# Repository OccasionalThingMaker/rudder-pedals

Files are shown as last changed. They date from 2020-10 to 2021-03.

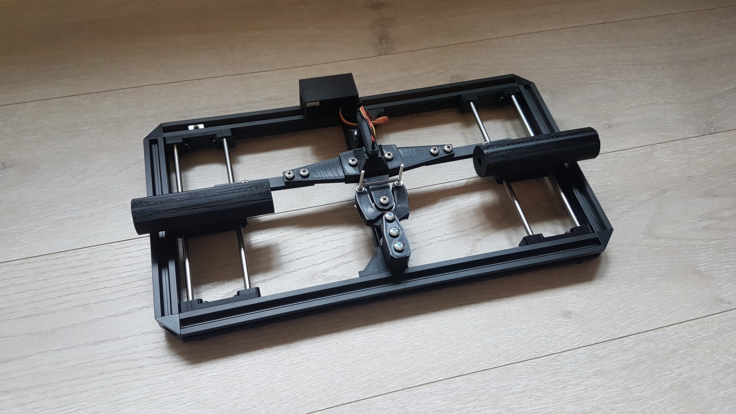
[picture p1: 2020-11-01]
Pictures/1.jpg

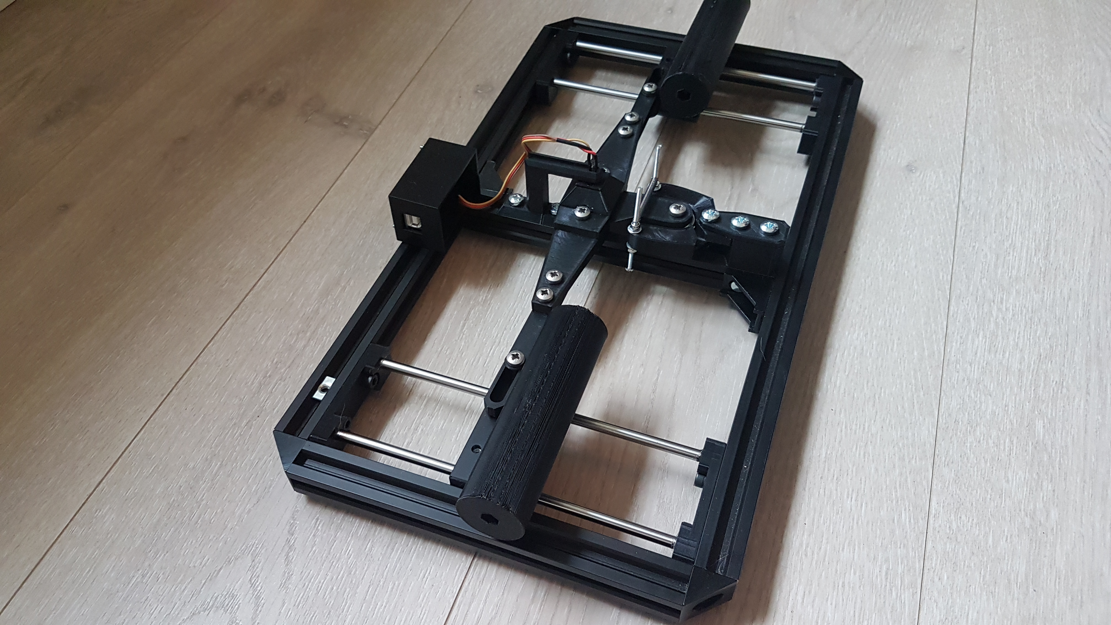
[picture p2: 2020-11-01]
Pictures/2.jpg

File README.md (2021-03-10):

# rudder-pedals

This is an ongoing project where I'm building rudder pedals for use in flight-sims from scratch.
The aim is to have rudder pedals with working brakes, with the pedals themselves modelled after the venerable F14 Tomcat pedals.
The mechanism is made from scratch by yours truly, with inspiration from various sources.

The goal is to make a pair of pedals that are:
* Easy to make (Requiring few tools, and a small 3D printer)
* Reasonably cheap
* Accurate and well functioning
* Free to download

Status as of writing:
The pedals are working and I'm starting to use them while "flying". 
I still have to fix some small details, like the box for the bodnar control board.
I've decided to postpone work on the full pedals with brake mechanism until I've I've finished all the details and the documentation.
The STEP files are not complete, nor checked for faults.

Contact me on reddit:
https://www.reddit.com/user/OccasionalThingMaker/

Check out r/HotasDIY for more inspiration and questions
https://www.reddit.com/r/HotasDIY/

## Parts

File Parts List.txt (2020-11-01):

This is a list of all the parts needed.

THIS LIST IS NOT COMPLETE

List of parts used

20x20 Aluminum extrusion - 2x 40cm, 3x 20cm
20x20 Corner brackets - 4x
20x20 Corner brackets - 2x
20x20
Metal rods - 4x 20cm rods, ø=6mm
LM6UU - 8x
T-nuts - 25-pack
M5 screws
M6 screws - 8x - For the four corners
LeoBodnar BU0836A 12-Bit Joystick Controller
LeoBodnar Hall sensor
Neodymium magnets - 2x

List of tools used
Thread tapper - M6 - For making threads in the extrusions so you can fasten the corner brackets
3D printer
Screw drivers
Soldering iron

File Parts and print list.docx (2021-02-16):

Buy list
Item | Qty | Usage | Picture | Link | Example price

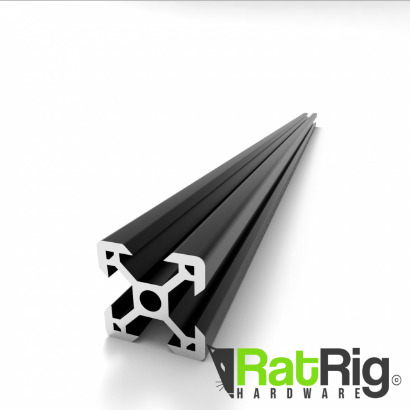
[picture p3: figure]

20x20 Aluminium extrusion 20cm | 3 | To make the frame. | | https://www.ratrig.com/aluminium-profiles/v-slot-2020/v-slot-2020-638.html | €11.25 (for 150cm)
20x20 Aluminium extrusion 40cm | 2

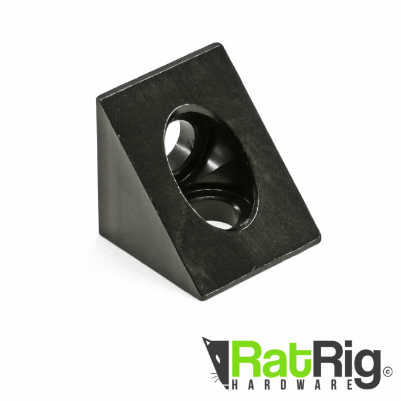
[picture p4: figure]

Corner connector | 4 | To connect the extrusions in the frame. You will need to tap the extrusions to make threads. | | https://www.ratrig.com/hardware2/openbuilds/brackets/openbuilds-90-degree-angle-corner-connector.html | €11.04

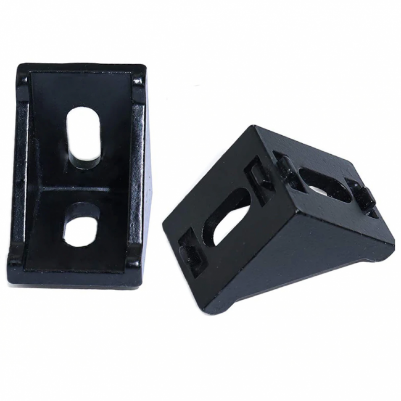
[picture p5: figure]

Corner bracket | 2 | To connect the middle 20cm extrusion. | | https://www.ratrig.com/hardware2/openbuilds/brackets/cast3030-black.html | €1.80

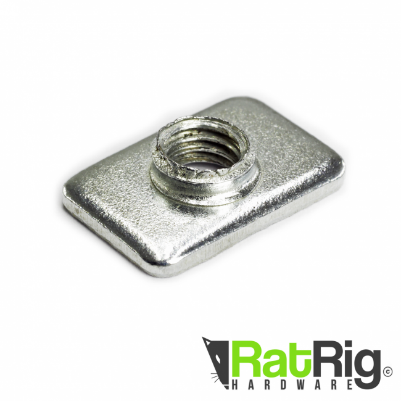
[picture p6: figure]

T-Nuts (25 Pack) | 1 | To connect all the hardware to the extrusions. M5 threads | | https://www.ratrig.com/hardware2/openbuilds/nuts-spacers-washers/openbuilds-tee-nuts-25-pack.html | €4.05

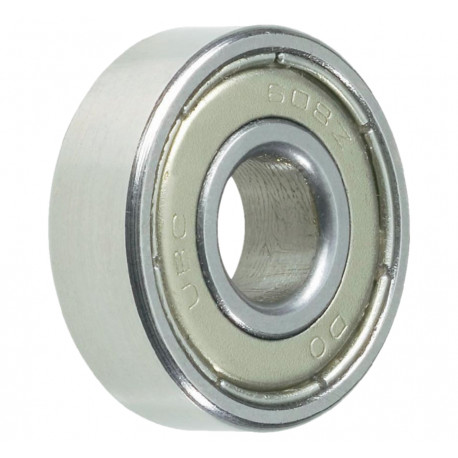
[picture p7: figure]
Bearing 608 2Z

Ball bearing 608Z | 2 | | | https://shop.prusa3d.com/en/mini/1108-bearing-608-2z.html | €2.14

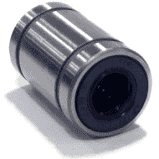
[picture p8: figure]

Linear bearing LM6UU | 8 | To slide on the rods. Need to fit 6mm diameter rods. | | https://www.romasterl.com/index.php?main_page=product_info&products_id=40302 | €24.72
Rubber feet | 4 | | | https://www.ratrig.com/hardware2/openbuilds/general-hardware/slider-bumper-kit-pair.html
Rods 20cm ø=6mm | 4 | For the pedals to slide along.
Spring | 1
mm M5 Screw
mm M5 Screw
mm M5 Screw
mm M5 Screw
M5 nut
M5 Nyloc nut
mm M3 Screw
mm M3 Screw
mm M3 Screw
M3 nut
M3 Nyloc nut

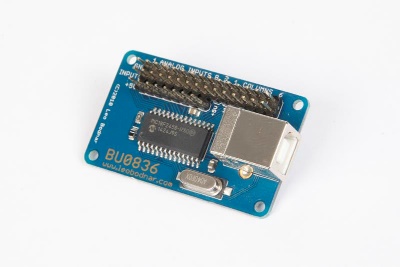
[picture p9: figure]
BU0836A 12-Bit Joystick Controller

BU0836A 12-Bit Joystick Controller | 1 | | | http://www.leobodnar.com/shop/index.php?main_page=product_info&cPath=94&products_id=204 | 24.99

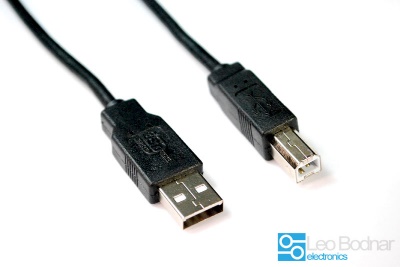
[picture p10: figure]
3m USB A to B cable

USB A to B cable | 1 | | | http://www.leobodnar.com/shop/index.php?main_page=product_info&products_id=270 | 3.87
Magnetic (Hall effect) sensor Allegro A1302 | 1 | | | http://www.leobodnar.com/shop/index.php?main_page=product_info&cPath=103_82&products_id=195 | 2.76

Cable with 3 pin connector plug attached - 30cm ( 12in )

Cable with 3 pin connector plug attached | 1 | | | http://www.leobodnar.com/shop/index.php?main_page=product_info&cPath=83&products_id=202 | 1.65
| | | | | 88,27

Print list
Tool list
3D-printer
Screw drivers
Soldering iron

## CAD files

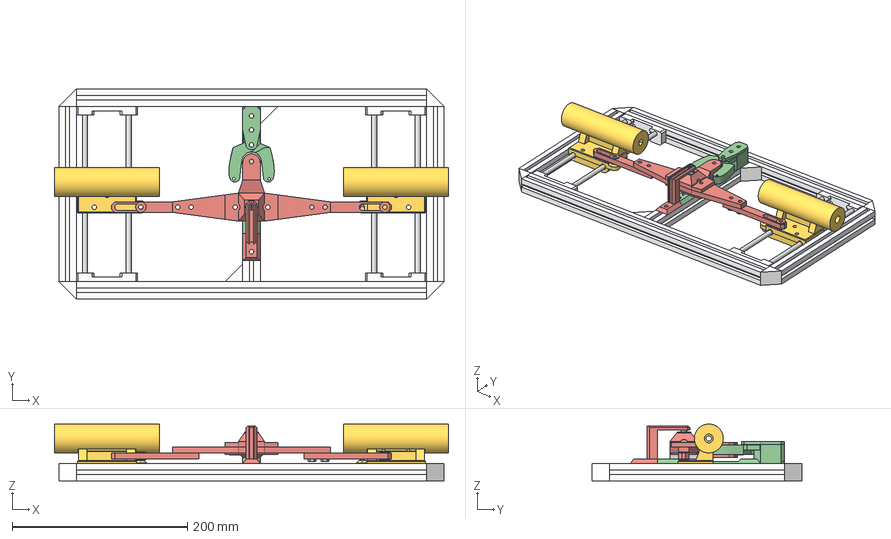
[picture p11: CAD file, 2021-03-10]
STEP files/all pieces.step
449.7 x 240.0 x 65.0 mm
Peddals v10
Peddals v10(Mirror)
Pedal sled v8(Mirror)

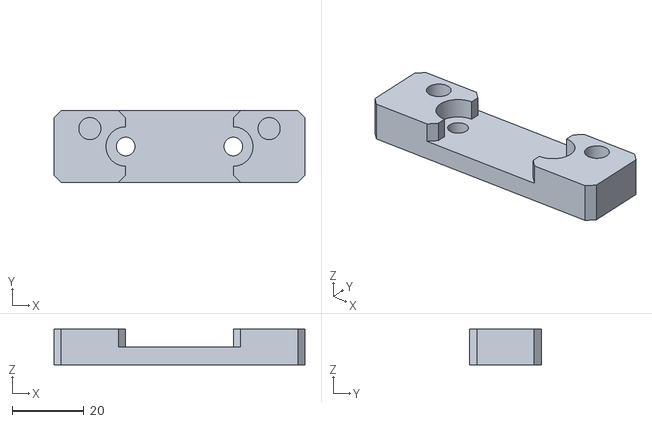
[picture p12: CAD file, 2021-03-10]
STLs/rod-bracket v2.stl
70.0 x 20.0 x 10.0

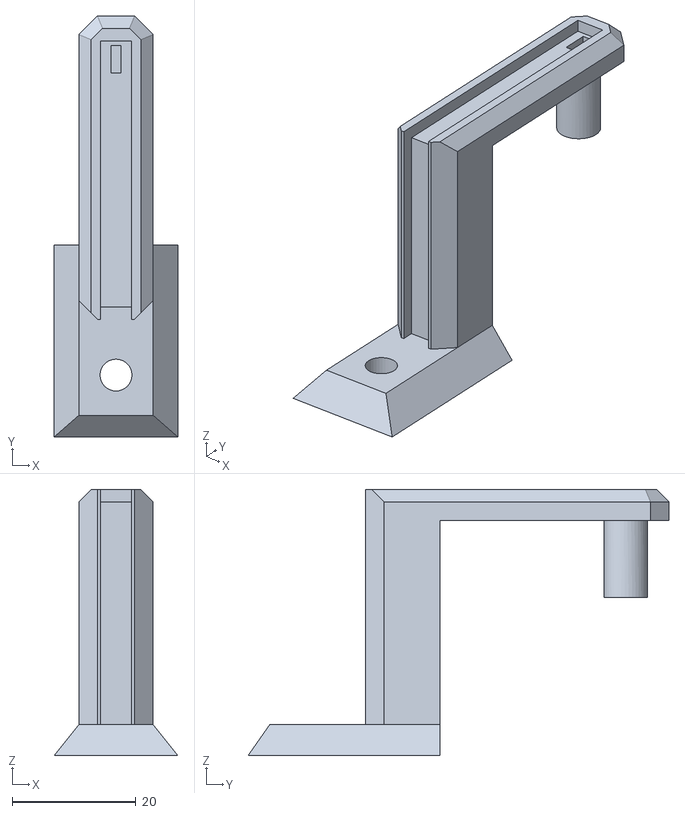
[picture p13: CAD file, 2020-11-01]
STLs/hall tower.stl
20.0 x 68.0 x 43.0

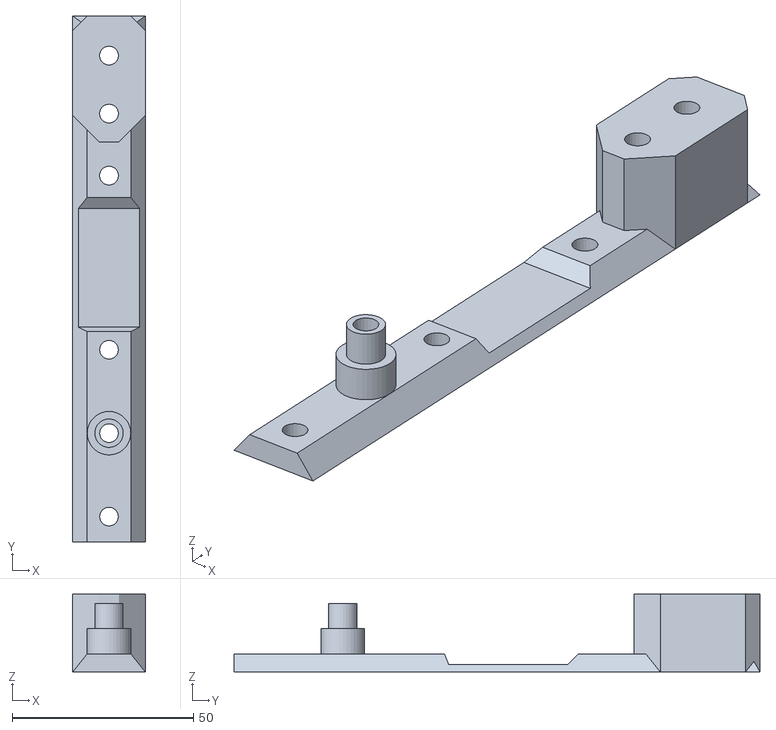
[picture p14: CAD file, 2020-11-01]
STLs/Base.stl
20.0 x 145.0 x 21.5

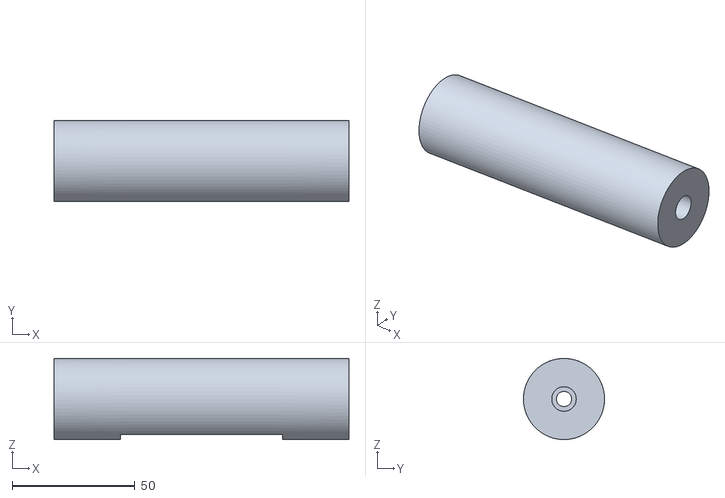
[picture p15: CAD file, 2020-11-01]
STLs/Pedal Placeholder.stl
120.0 x 33.0 x 33.0

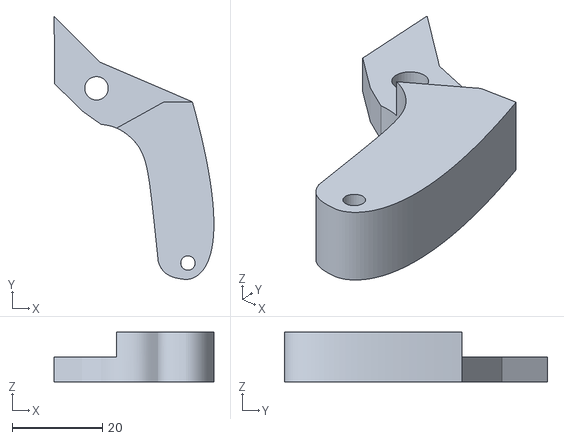
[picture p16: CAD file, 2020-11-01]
STLs/Cam Soft center.stl
35.4 x 58.3 x 11.0

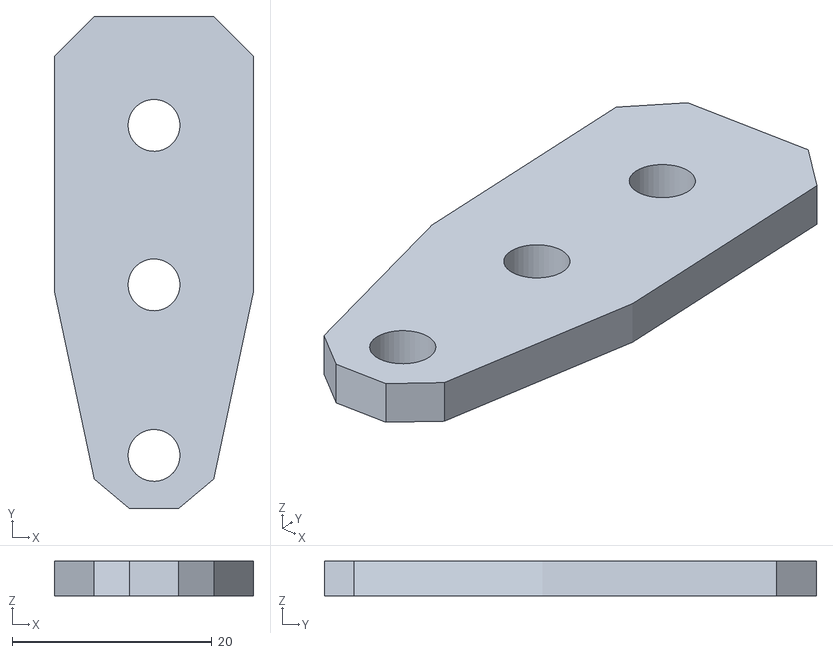
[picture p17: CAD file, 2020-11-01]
STLs/Cam Tower Lid.stl
20.0 x 49.3 x 3.50

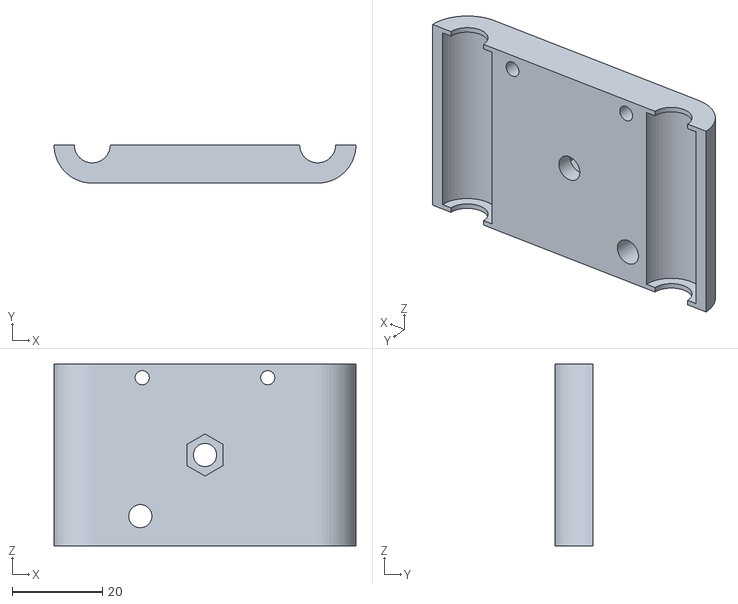
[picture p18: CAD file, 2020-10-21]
STLs/Pedal Carriage Left Lower.stl
67.0 x 8.50 x 40.3

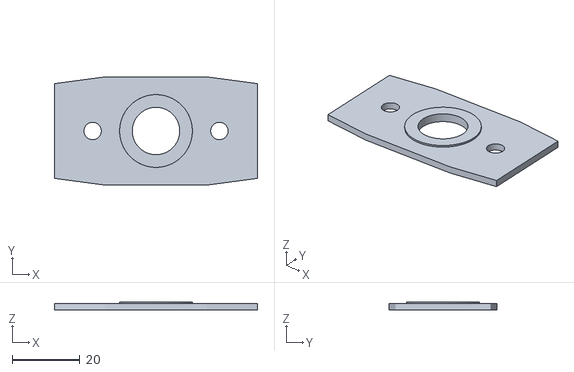
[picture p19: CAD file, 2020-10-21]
STLs/Seesaw Bottom plate.stl
60.0 x 32.0 x 2.50

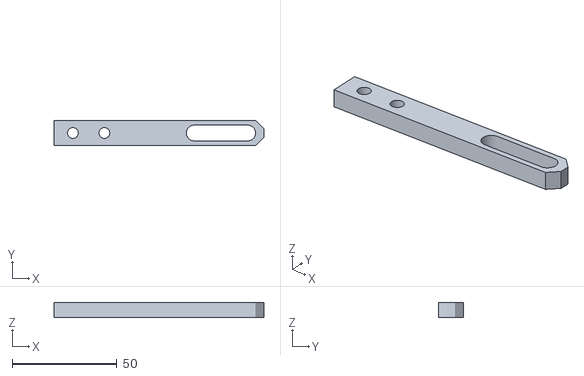
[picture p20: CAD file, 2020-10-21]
STLs/Seesaw Arm extender.stl
100.0 x 12.0 x 7.00

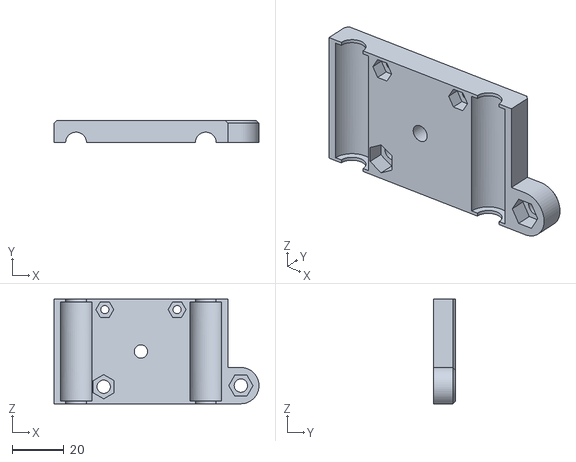
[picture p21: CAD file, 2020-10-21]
STLs/Pedal Carriage Left Upper.stl
79.0 x 8.50 x 40.3

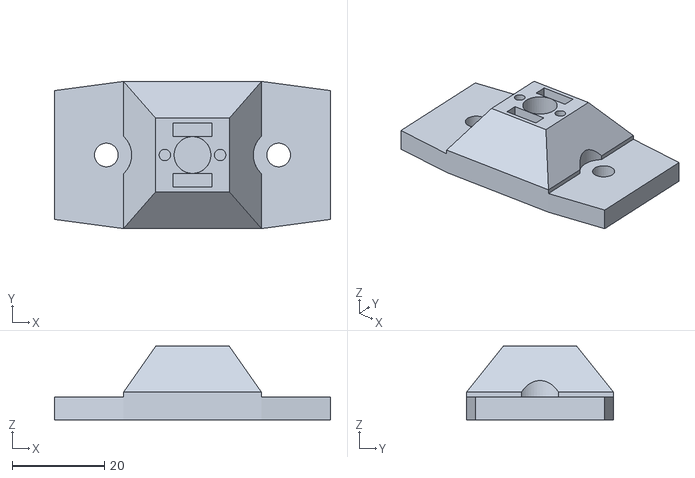
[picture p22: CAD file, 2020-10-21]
STLs/Seesaw Magnet holder.stl
60.0 x 32.0 x 16.0

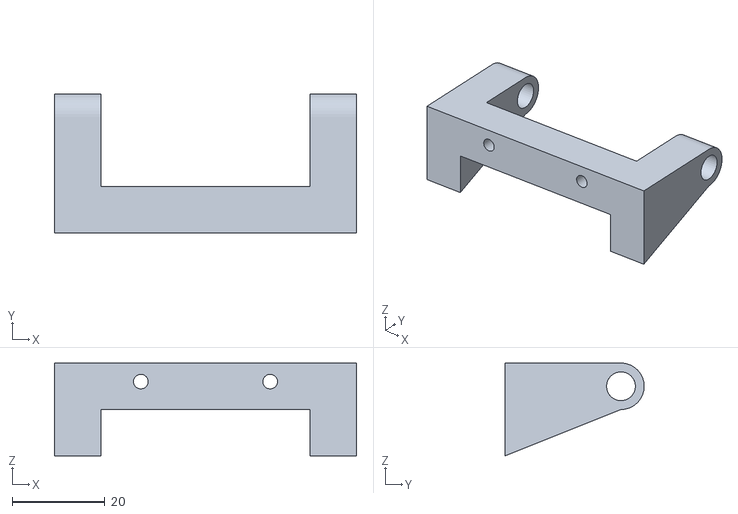
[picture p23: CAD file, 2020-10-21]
STLs/Pedal Carriage Hinge.stl
65.0 x 30.0 x 20.0

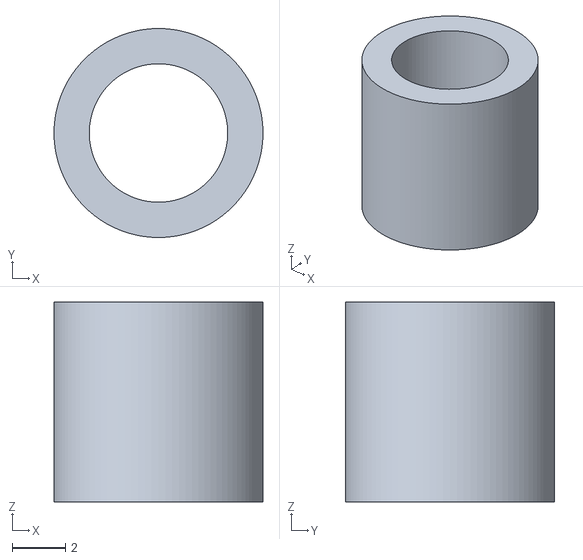
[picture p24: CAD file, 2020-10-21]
STLs/Seesaw Ball Bearing Core.stl
7.85 x 7.85 x 7.50

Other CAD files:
STLs/Pedal Carriage Right Lower.stl
STLs/Pedal Carriage Right Upper.stl
STLs/Arm Extender to Carriage Bearing.stl
STLs/Bodnar Box.stl
STLs/Seesaw Magnet lid.stl
STLs/seesaw.stl

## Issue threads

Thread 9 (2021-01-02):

Redesign pedal carriage to only use three bearings each

OccasionalThingMaker, 2021-01-02:

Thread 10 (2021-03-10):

Missing STL for rod housings

roboboogie, 2021-03-10:
Appolgies if I'm wrong but we're possibly missing the socket for the ends of the metal rods as pictured?

OccasionalThingMaker, 2021-03-10:
You're right. Uploaded it now as "rod-bracket v2.stl"
I would advice to test print parts of the pieces and check how they fit, as the tolerances were made for my printer. You can adjust them as needed with "XY Size Compensation" (name in prusaslicer, could be different in other slicers) as needed.

roboboogie, 2021-03-10:
Thank you! Really appreciate you sharing tall of this.

Closed 2021-03-10.

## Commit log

2020-10-21 Add files via upload
    The first, semifunctioning version.
    [Arm extender.stl, Bearing core.stl, Bearing.stl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]
2020-10-24 file and folder cleanup
    [Arm extender.stl, Bearing core.stl, Bearing.stl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]
2020-11-01 STLs
    Updated STLs and cleaned up naming scheme
    [Arm Extender to Carriage Bearing.stl, Base.stl, Cam Soft center.stl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]
2021-03-10 uploaded step files
    [all pieces.step]
